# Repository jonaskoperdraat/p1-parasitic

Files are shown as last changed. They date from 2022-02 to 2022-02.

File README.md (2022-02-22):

# p1-parasitic
Project with the goal to build a wifi and/or BLE enabled P1-gateway

## P1-gateway

I have a smart meter and want to be able to access readings from it in a (near) realtime fashion. 

## Parasitic

I currently don't have an additional power outlet near the meter so a parasitic device, running of the power supplied by the P1 port would be preferable.

The power supplied by the P1 port is limited, so that is something to take into account.

## ESP32 / M5stick

I have a M5stick laying around with which I've managed to read from the P1 port and post to an MQTT topic before. This also has the benefit of having a battery which might be used as a buffer to supply current for the peak power required to send data over WiFi, whilst charging off the P1 power supply when the M5stick is dormant.

## Smart meter

The meter in my home is a ISKRA AM550-TD2 3-phase meter.

### P1 port

I have confirmed that the P1 port has a 5V power supply on pin #1 and #6.

:question: will the P1 port be able to supply enough power to charge the battery of the M5stick
:question: how much current can the P1 supply?
:question: how much current is required to get the M5stick to charge it's internal battery?

As I don't have the equipment at hand, nor the knowledge to test the max current the P1 port can supply, I will have to find out empirically whether or not the P1 port and the M5stick are a good match.

#### Charging the M5stick

The M5stick has a 80mAh battery and is configured by default to charge at 100mA.

Even though elsewhere a max current draw of 100mA is mentioned [^1] for DSMR 4.x, and no voltage on pins #1 and #2 for the ISKRA AM550, [^1] also mentions that the ISKRA AM550 uses ESMR5.0, which is supposed to be able to output 250mA of current.
I haven't been able to find a spec for ESMR5.0, but [ref/DSMRv5.0.pdf] is a spec for "DSMR5.0 (Dutch Smart Meter Requirements)" which metions a max output of 250mA. The device itself has a label on it with "SMR 5.0", so I'm hoping ESMRv5.0 and DSMRv5.0 are kinda the same thing and the meter will just supply 250mA.

This might even be enough to not have to worry too much about deep sleep...

##### Test setup
Let's see if this configuration will run the M5Stick-C

```
            5V< ───────────┐
            3V3            └──────────── #1 +5V Power supply
            BAT                          #2 Data request
 M5STICK-C  G06                          #3 Data GND         P1
            G36                          #4 -
            G26                          #5 Data line - Open collector
            5V>            ┌──────────── #6 Power GND
            GND ───────────┘
```

In order to test whether the M5stick can operate off of the M5stick, without worrying about reading the telegrams yet, I'll run the following test:

* Attempt to power the M5Stick-C through above cirquit
* Run the M5Stick-C with the following program:
    * On wake up:
        * Connect to WiFi
        * Connect to MQTT
        * publish battery stats to MQTT topic
        * Go to sleep for 10 seconds
* See how long the device lasts. Without power supply, this program can run roughly 3.5 hours.

The P1 port supplies enough power for the M5Stick to run for a prolonged period. The current setup has been
with putting the M5Stick into deep sleep and waking every 10s to connect to WiFi, MQTT, read the P1 data and
publish to MQTT.

## Implementation

I've thought about a number of 'clever' ways to wait for telegrams and to go into deep sleep mode in between.
Like being woken by a timer, or by incoming telegrams. This was mostly motivated by the thought that the P1
port would only supply enough power to charge whilst in deep sleep, and not for sending. However, these 
methods add complexity and might not even be needed, seeing as the P1 port is supposed to be able to provide
250mA.

So I'm starting out (relatively) simple.

> * Connect to WiFi
> * Connect to MQTT
> * Wait for telegram
>   * Upon receiving telegram, send to MQTT \
>     Each telegram will be converted into a JSON message and sent as a single message to MQTT.
>     This can be done using [this library](https://github.com/matthijskooijman/arduino-dsmr)
>   * Wait for next telegram
>
> Display:
>   * WiFi status
>   * MQTT status
>   * \# telegrams received
>   * \# telegrams sent to MQTT
>
> Connection mechanism:
> * Whenever WiFi is disconnected
>   * Attempt to connect
>       * If unsuccessfull, wait _d_ seconds \
>         _d_ being determined by number of attempts, _n_ made so far:
>         | *n* | 1  | 2  | 3  | 4+ |
>         | --- | -: | -: | -: | -: |
>         | ***d*** | 5  | 10 | 30 | 60 |
>       * If successful, reset _n_.
> * Whenever MQTT is disconnected, follow the same schema for connecting to WiFi,
>   *only if* WiFi is connected. Otherwise, do nothing.

## Notes

The M5stickC suffers from a bug where uploading times out. This can be remidied by either shorting `G0` to `GND` while programming using a dupont line, or by updating the firmware if you're brave enough [^2].
update: I've updated the firmware, ridding the device of said bug.

## Log

**17 feb 2021, 11:55**

Just connecting the M5stick to the P1 port using above schema does not show any voltage reported on `v_5vin` or current on `i_5vin`.

:question: Perhaps there's a hardware or configuration adjustment needs to be done before this can be used? 
:question:Or the P1 port might not be able to supply the requested current? 

**17 feb 2021, 17:00**

Apparently I just had +5V and GND mixed up. Sorting this out runs the M5stick just fine.

**19 feb**

I've created the [electronics design](hardware/readme.md) on a breadboard. This turned out to work and I was able
to read P1 messages coming from the meter.

**20 feb** 

I've converted the electronics design from breadboard to prototype PCB as well as designed an [enclosure](hardware/casing).
The M5Stick has been running fine in the 10s sleep/measure cycle. 

## References

[^1] Domoticx Knowledge Center - P1 poort slimme meter (hardware)
[^2] (M5StickC/ATOM on MacOS Catalina can't upload/ ESP32: Timed out waiting for packet header solution (Solved)

[^1]: http://domoticx.com/p1-poort-slimme-meter-hardware/
[^2]: https://forum.m5stack.com/topic/1591/m5stickc-atom-on-macos-catalina-can-t-upload-esp32-timed-out-waiting-for-packet-header-solution-solved

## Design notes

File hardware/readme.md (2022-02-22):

# Hardware

This page should treat any hardware considerations that where made.

## Electronics

The software library I intend to use for reading the P1 telegrams, supports switching the data request line
through a GPIO pin. 

Also, the data signal needs to be inverted and converted to 3.3V. This schema does that:

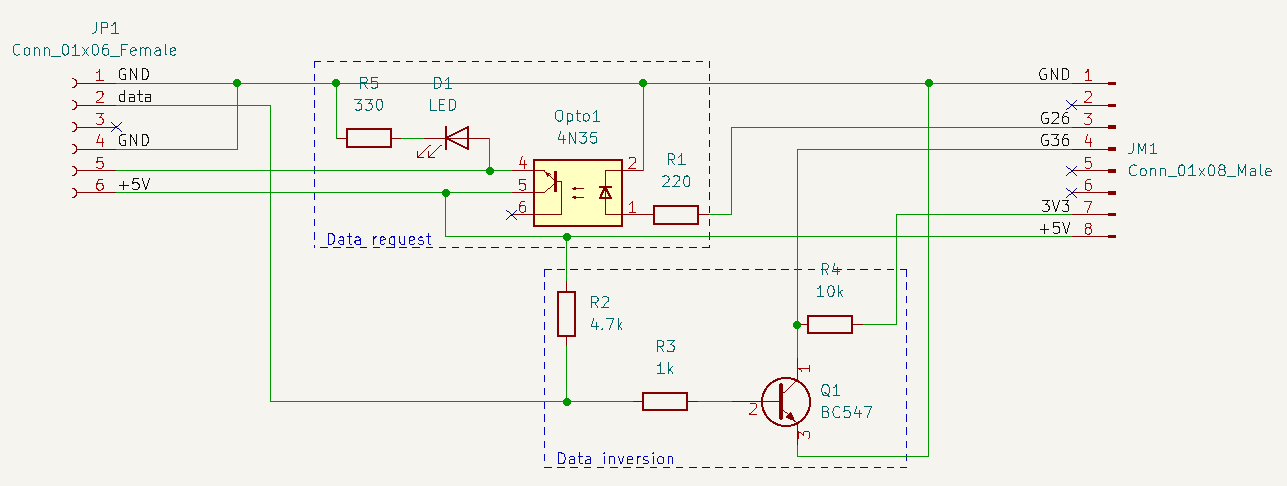
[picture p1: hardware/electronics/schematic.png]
Schematic


*note*: the `JP1` connector is number in reverse. This was my way of orienting the connector the right way
on the PCB.

## Casing

I designed a case that will allow me to mount the case to the meter housing and still give me easy access 
to the M5Stick when needed.

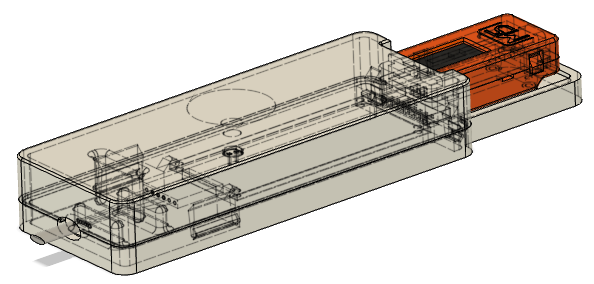
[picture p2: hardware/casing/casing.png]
Casing


The fusion 360 design can be found here: https://a360.co/3IbdbrX

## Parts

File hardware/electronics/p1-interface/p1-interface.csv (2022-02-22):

Source: | /Users/jonas/Projects/Prive/p1-parasitic/schematics/p1-interface/p1-interface.kicad_sch
Date: | 2022 February 19, Saturday 23:25:41
Tool: | Eeschema (6.0.2-0)
Generator: | /Applications/KiCad/KiCad.app/Contents/SharedSupport/plugins/bom_csv_grouped_by_value.py
Component Count: | 9
Individual Components:
Item | Qty | Reference(s) | Value | LibPart | Footprint | Datasheet
 |  | D1 | 1N5819 | Diode:1N5819 | Diode_THT:D_DO-41_SOD81_P10.16mm_Horizontal | http://www.vishay.com/docs/88525/1n5817.pdf
 |  | JM5 | Conn_01x08_Male | Connector:Conn_01x08_Male | Connector_PinHeader_2.54mm:PinHeader_1x08_P2.54mm_Horizontal | ~
 |  | JP1 | Conn_01x06_Female | Connector:Conn_01x06_Female | Connector_PinHeader_2.54mm:PinHeader_1x06_P2.54mm_Horizontal | ~
 |  | Opto1 | 4N35 | Isolator:4N35 | Package_DIP:DIP-6_W7.62mm | https://www.vishay.com/docs/81181/4n35.pdf
 |  | Q1 | BC547 | Transistor_BJT:BC547 | Package_TO_SOT_THT:TO-92_Inline | https://www.onsemi.com/pub/Collateral/BC550-D.pdf
 |  | R1 | 220 | Device:R | Resistor_THT:R_Axial_DIN0207_L6.3mm_D2.5mm_P10.16mm_Horizontal | ~
 |  | R2 | 10k | Device:R | Resistor_THT:R_Axial_DIN0207_L6.3mm_D2.5mm_P10.16mm_Horizontal | ~
 |  | R3 | 1k | Device:R | Resistor_THT:R_Axial_DIN0207_L6.3mm_D2.5mm_P10.16mm_Horizontal | ~
 |  | R4 | 1k | Device:R | Resistor_THT:R_Axial_DIN0207_L6.3mm_D2.5mm_P10.16mm_Horizontal | ~
Collated Components:
Item | Qty | Reference(s) | Value | LibPart | Footprint | Datasheet
1 | 1 | D1 | 1N5819 | Diode:1N5819 | Diode_THT:D_DO-41_SOD81_P10.16mm_Horizontal | http://www.vishay.com/docs/88525/1n5817.pdf
2 | 1 | JM5 | Conn_01x08_Male | Connector:Conn_01x08_Male | Connector_PinHeader_2.54mm:PinHeader_1x08_P2.54mm_Horizontal | ~
3 | 1 | JP1 | Conn_01x06_Female | Connector:Conn_01x06_Female | Connector_PinHeader_2.54mm:PinHeader_1x06_P2.54mm_Horizontal | ~
4 | 1 | Opto1 | 4N35 | Isolator:4N35 | Package_DIP:DIP-6_W7.62mm | https://www.vishay.com/docs/81181/4n35.pdf
5 | 1 | Q1 | BC547 | Transistor_BJT:BC547 | Package_TO_SOT_THT:TO-92_Inline | https://www.onsemi.com/pub/Collateral/BC550-D.pdf
6 | 1 | R1 | 220 | Device:R | Resistor_THT:R_Axial_DIN0207_L6.3mm_D2.5mm_P10.16mm_Horizontal | ~
7 | 1 | R2 | 10k | Device:R | Resistor_THT:R_Axial_DIN0207_L6.3mm_D2.5mm_P10.16mm_Horizontal | ~
8 | 2 | R3, R4 | 1k | Device:R | Resistor_THT:R_Axial_DIN0207_L6.3mm_D2.5mm_P10.16mm_Horizontal | ~

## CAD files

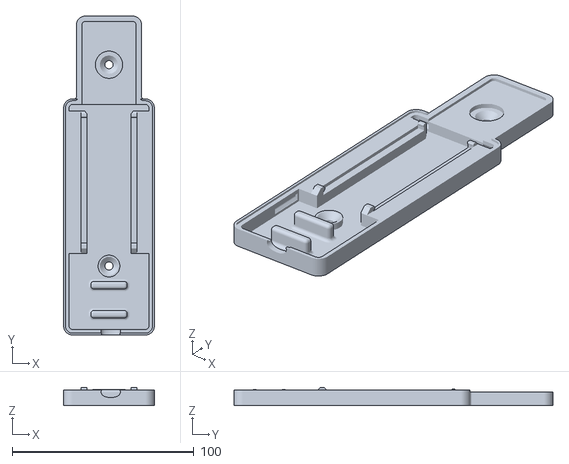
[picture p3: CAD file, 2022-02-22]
hardware/casing/bottom_v1.stl
50.0 x 175.6 x 10.1

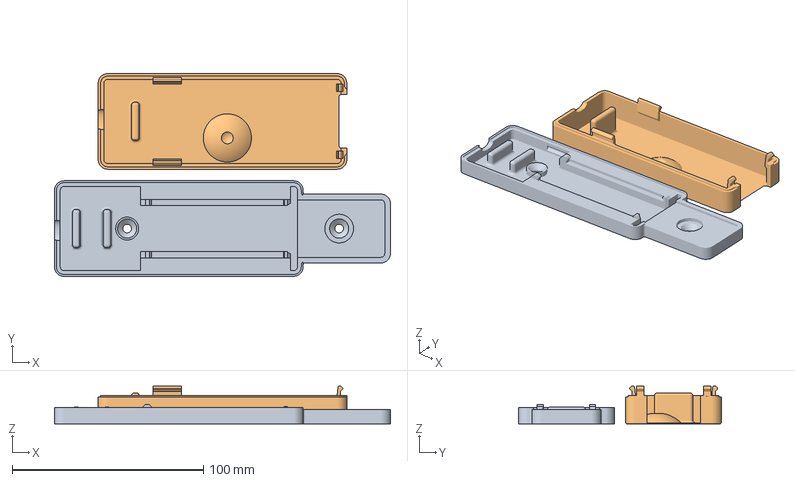
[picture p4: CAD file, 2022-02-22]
hardware/casing/casing_v1.3mf
175.6 x 106.0 x 19.8 mm
bottom_v1.stl

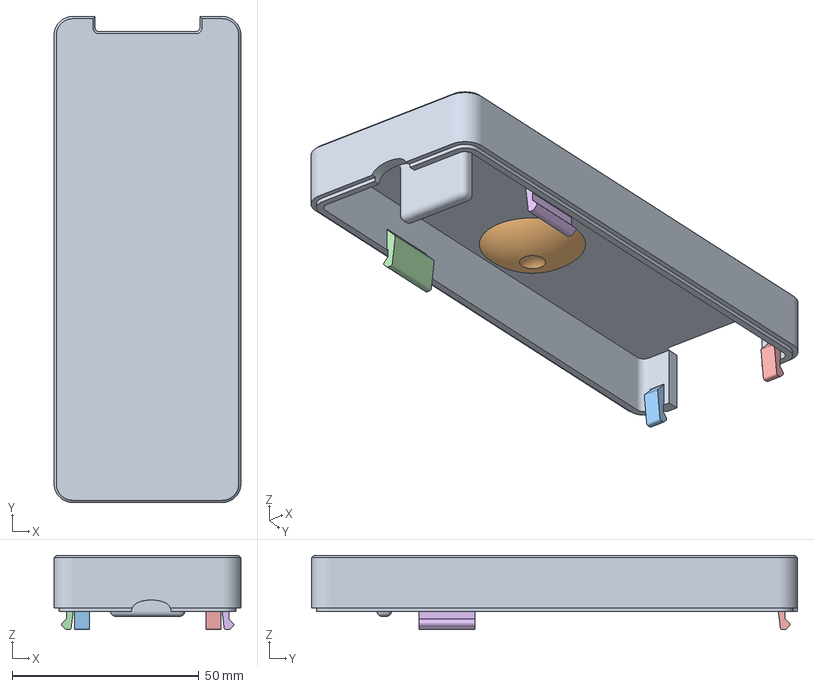
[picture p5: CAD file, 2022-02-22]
hardware/casing/top_v1.3mf
50.0 x 130.0 x 19.8 mm

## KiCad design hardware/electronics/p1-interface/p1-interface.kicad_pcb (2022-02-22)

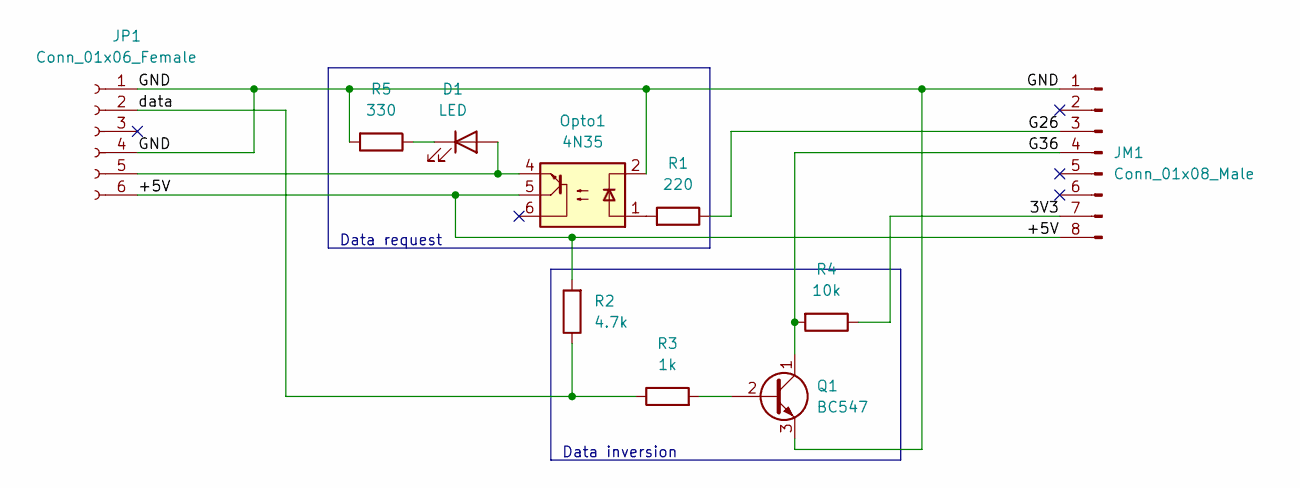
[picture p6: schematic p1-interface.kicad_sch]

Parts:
D1: LED; LED_D5.0mm
JM1: Conn_01x08_Male; PinHeader_1x08_P2.54mm_Horizontal
JP1: Conn_01x06_Female; PinHeader_1x06_P2.54mm_Horizontal
Opto1: 4N35; DIP-6_W7.62mm
Q1: BC547; TO-92_Inline_Wide
R1: 220; R_Axial_DIN0207_L6.3mm_D2.5mm_P10.16mm_Horizontal
R2: 4.7k; R_Axial_DIN0207_L6.3mm_D2.5mm_P10.16mm_Horizontal
R3: 1k; R_Axial_DIN0207_L6.3mm_D2.5mm_P10.16mm_Horizontal
R4: 10k; R_Axial_DIN0207_L6.3mm_D2.5mm_P10.16mm_Horizontal
R5: 330; R_Axial_DIN0207_L6.3mm_D2.5mm_P10.16mm_Horizontal

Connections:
/3V3: JM1.7, R4.1
/+5V: JM1.8, JP1.6, Opto1.5, R2.2
/G26: JM1.3, R1.1
/G36: JM1.4, Q1.1 (C), R4.2
/GND: JM1.1, JP1.1, JP1.4, Opto1.2, Q1.3 (E), R5.2
/data: JP1.2, R2.1, R3.1
unnamed: D1.1 (K), R5.1
unnamed: D1.2 (A), JP1.5, Opto1.4
unnamed: Q1.2 (B), R3.2
unnamed: Opto1.1, R1.2

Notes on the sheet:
Data request
Data inversion

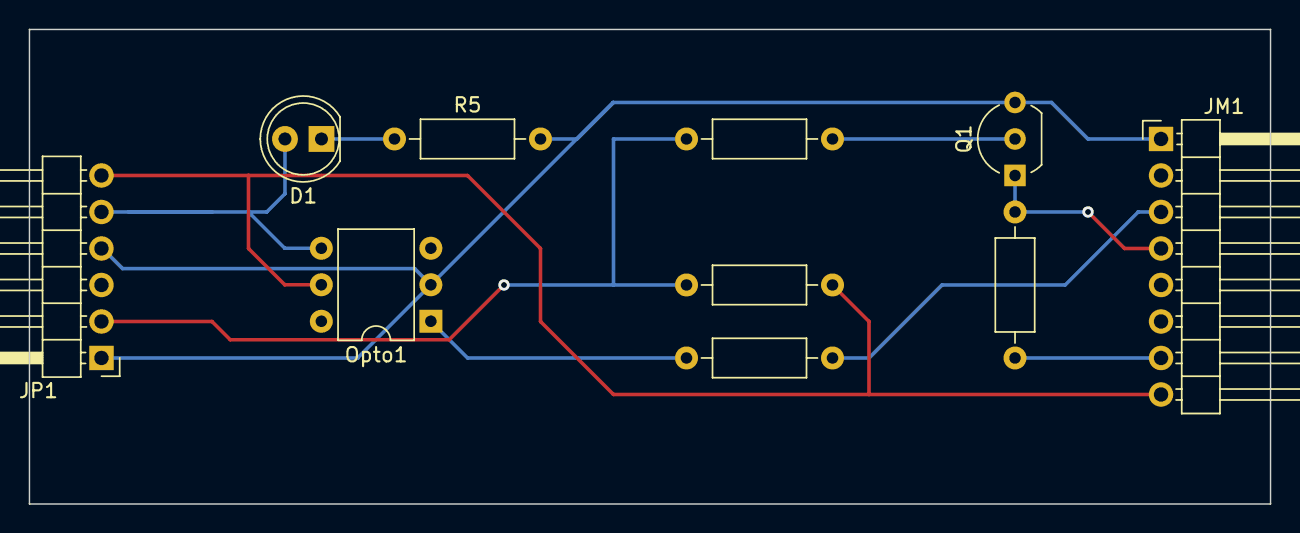
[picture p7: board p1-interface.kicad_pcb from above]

Board: 2 copper layers, 86.4 x 33.0 mm, 10 parts (0 on the bottom side), 10 nets.
